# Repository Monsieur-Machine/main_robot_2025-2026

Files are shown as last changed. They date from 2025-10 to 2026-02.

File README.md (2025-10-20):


# Main Robot 2025-2026

## Description
Main robot code, pcbs and 3d modeling for the Eurobot 2025-2026 competition.

## LICENSES
- This project is open-source : you can redistribute and/or modify it under the term of the **GNU GPLv3**.
  Copyright (C) 2025 Riombotique. See [LICENSE](LICENSE) or [gnu.org/licenses/gpl-3.0.html](https://www.gnu.org/licenses/gpl-3.0.html).

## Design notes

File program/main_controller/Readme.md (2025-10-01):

Motion controler code for the RPI Pico (RP2040)
===============================================

This project is the main controller firmware for the RPI Pico (RP2040), designed for the Eurobot 2025 Cup.

I2C description
-----------------------------------------------

The robot’s I2C communication works as follows:
 * Send the device address + R/W bit (to select read or write mode).
 * Send the target register address (to read from or write to).
 * Read or write the register data. Multiple registers can be read/written sequentially, with the address auto-incrementing after each operation.

This code is designed to be the master in the i2c communication.

|Register |R/W|Description |Encoding |
|---|:-:|---|:---:|
| 0x00 | W | Speed motor 1 |**-128** - **127** |
| 0x01 | W | Speed motor 2 |**-128** - **127** |
| 0x02 | W | Speed motor 3 |**-128** - **127** |
| 0x03 | W | Speed motor 4 |**-128** - **127** |
| 0x04 | W | Servo 1 position selection | **0** - **1** |
| 0x05 | W | Servo 2 position selection | **0** - **1** |
| 0x06 | W | Servo 3 position selection | **0** - **1** |
| 0x07 | W | Servo 4 position selection | **0** - **1** |

Motors communication description
-----------------------------------------------

Motors are «connected» to their respective I2C buffer address.

To control a motor you need to write data to its adress of the form :

>```C
>int8_t speed;
>```

Value goes from **-128** to **127**.

Servo motors communication description
-----------------------------------------------

Servo motors are «connected» to their respective I2C buffer address.

To control a servo motor you need to write data to its adress of the form :

>```C
>uint8_t close;
>```

Value is 0 or 1 for the open or the close pos.

Internet communication description
-----------------------------------------------

The robot main_controller is a client connected to the wireless controller which is an udp server host. A buffer is used to store data received from host.

Speed on X and Y axis are not depending of the robot orientation.

Servo motors keep the same byte address in i2c buffer and udp payload.

|Byte |Description |Encoding |
|---|---|:---:|
| 0x00-01 | Robot angle (0x00 is the last significant byte) |**-180** - **180** |
| 0x02 | Speed x axis |**-128** - **127** |
| 0x03 | Speed y axis |**-128** - **127** |
| 0x04 | Servo 1 position selection | **0** - **1** |
| 0x05 | Servo 2 position selection | **0** - **1** |
| 0x06 | Servo 3 position selection | **0** - **1** |
| 0x07 | Servo 4 position selection | **0** - **1** |

Pinout description
-----------------------------------------------

|Pin |Description |GPIO Type  |
|----|---|---|
| 4  | I2C Bus SDA | I2C |
| 5  | I2C Bus SCL | I2C |

Motors placement
-----------------------------------------------

    ,-~***~-,
  /1         2\
 |             |
 |             |
 |             |
  \3         4/
    `-.....-'

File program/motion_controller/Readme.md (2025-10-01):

Motion controler code for the RPI Pico (RP2040)
===============================================

This project is a motion controller firmware for the RPI Pico (RP2040), designed for plug-and-play use with modular code and a clear architecture.

I2C description
-----------------------------------------------

The robot’s I2C communication works as follows:
 * Send the device address + R/W bit (to select read or write mode).
 * Send the target register address (to read from or write to).
 * Read or write the register data. Multiple registers can be read/written sequentially, with the address auto-incrementing after each operation.

This firmware is coded to be a slave when adressed. Its address is **0x09** which you can change if there is any conflict whit other hardware.

|Adress |R/W|Description |Encoding |
|---|:-:|---|:---:|
| 0x00  | W | Speed motor 1 |**-128** - **127** |
| 0x01  | W | Speed motor 2 |**-128** - **127** |
| 0x02  | W | Speed motor 3 |**-128** - **127** |
| 0x03  | W | Speed motor 4 |**-128** - **127** |
| 0x04  | W | Servo 1 position selection | **0** - **1** |
| 0x05  | W | Servo 2 position selection | **0** - **1** |
| 0x06  | W | Servo 3 position selection | **0** - **1** |
| 0x07  | W | Servo 4 position selection | **0** - **1** |

Motors communication description
-----------------------------------------------

Motors are «connected» to their respective I2C buffer address.

To control a motor you need to write data to its adress of the form :

>```C
>int8_t speed;
>```

Value goes from **-128** to **127**.

Servo motors communication description
-----------------------------------------------

Servo motors are «connected» to their respective I2C buffer address.

To control a servo motor you need to write data to its adress of the form :

>```C
>uint8_t close;
>```

Value is 0 or 1 for the open pos or the close pos.

Pinout description
-----------------------------------------------

|Pin |Description |GPIO Type  |
|----|---|---|
| 0  | Motor1 Speed | PWM |
| 1  | Motor2 Speed | PWM |
| 2  | Motor3 Speed | PWM |
| 3  | Motor4 Speed | PWM |
| 4  | Motor1 Dir1 | OUTPUT |
| 5  | Motor1 Dir2 | OUTPUT |
| 6  | Motor2 Dir1 | OUTPUT |
| 7  | Motor2 Dir2 | OUTPUT |
| 8  | Motor3 Dir1 | OUTPUT |
| 9  | Motor3 Dir2 | OUTPUT |
| 10 | Motor4 Dir1 | OUTPUT |
| 11 | Motor5 Dir2 | OUTPUT |
| 12 | Servo1 Angle | PWM |
| 13 | Servo2 Angle | PWM |
| 14 | Servo3 Angle | PWM |
| 15 | Servo4 Angle | PWM |
| 21 | I2C Bus SDA | I2C |
| 20 | I2C Bus SCL | I2C |

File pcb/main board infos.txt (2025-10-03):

# LMZ13608 configuration

Vin min = 9v
Vin max = 12v

Vout = 5v

## Enable resitors
Rent / Renb = (Vin min / 1.274) - 1

Vin min in volt
Rent and Renb same unit and above 5kΩ

Maybe 47kΩ for Rent and 7.75kΩ for Renb

## Output voltage resistors
Rfbt / Rfbb = (Vout / 0.795) – 1

Vout in volt
Rent and Renb in the range of 1.0 kΩ to 10.0 kΩ

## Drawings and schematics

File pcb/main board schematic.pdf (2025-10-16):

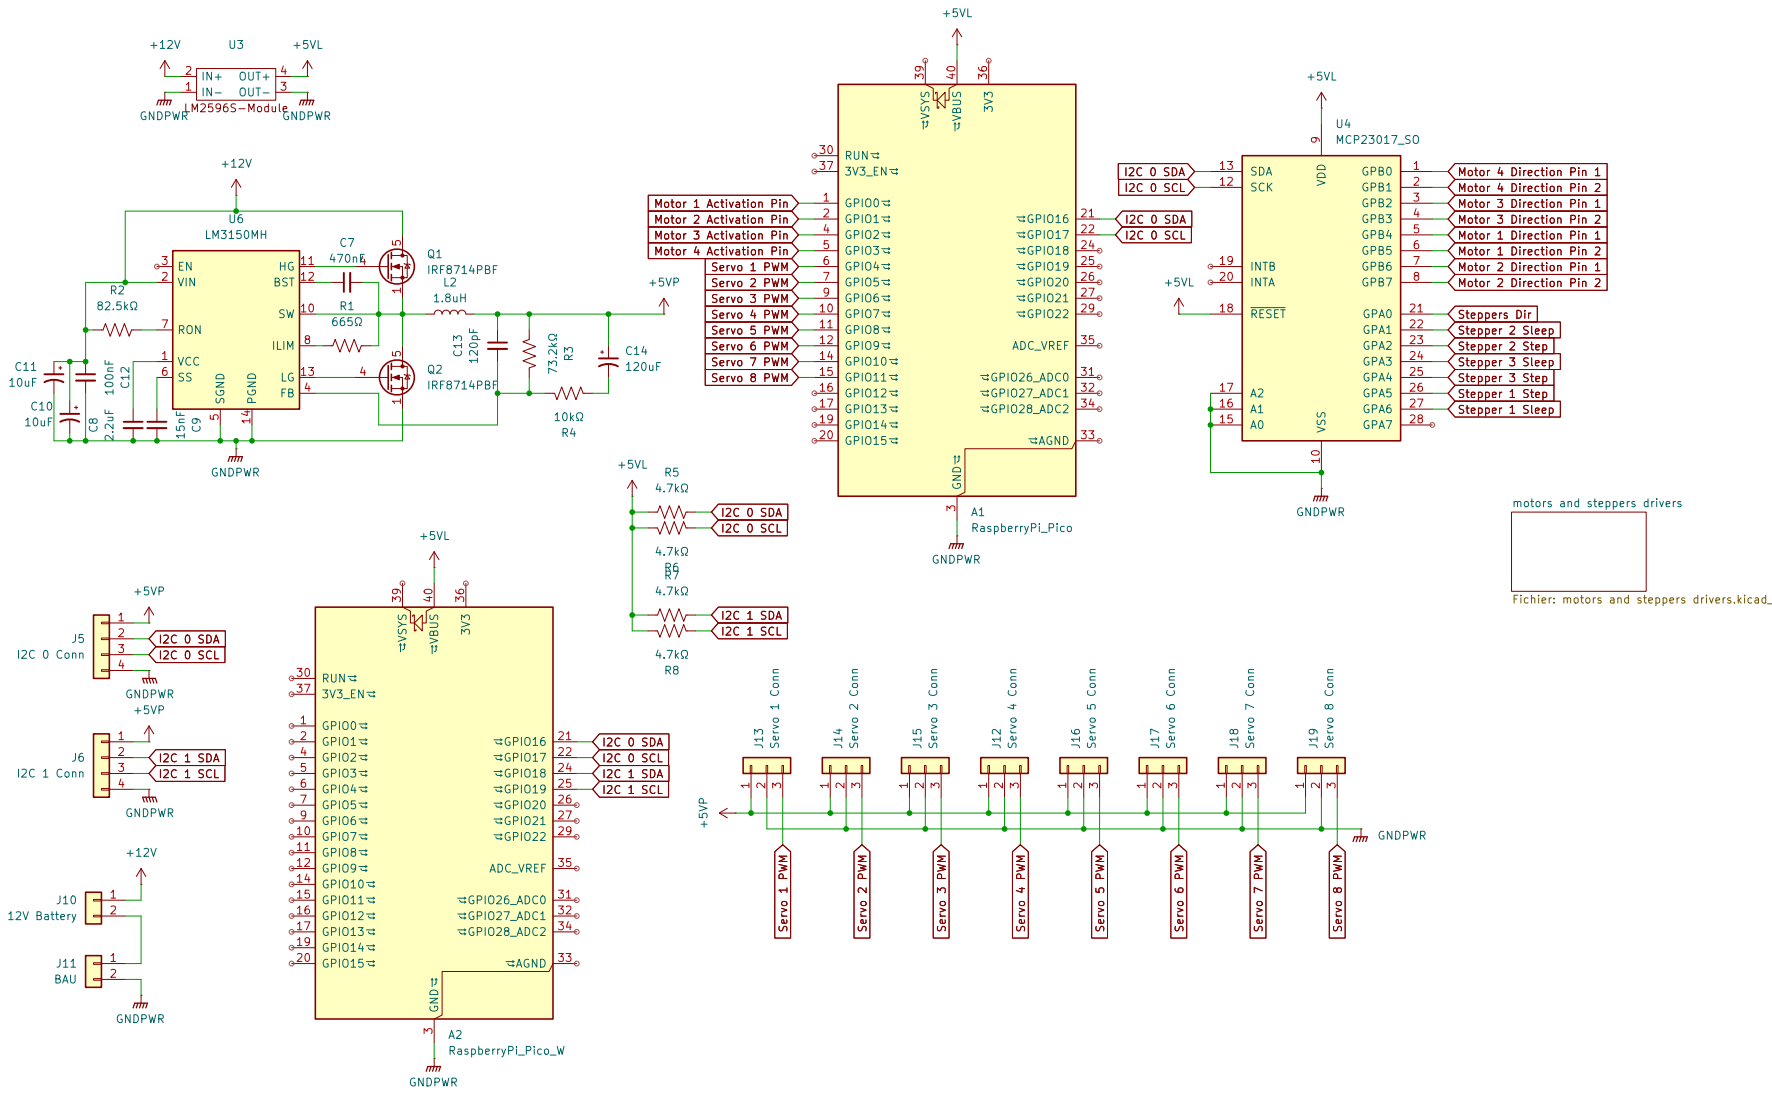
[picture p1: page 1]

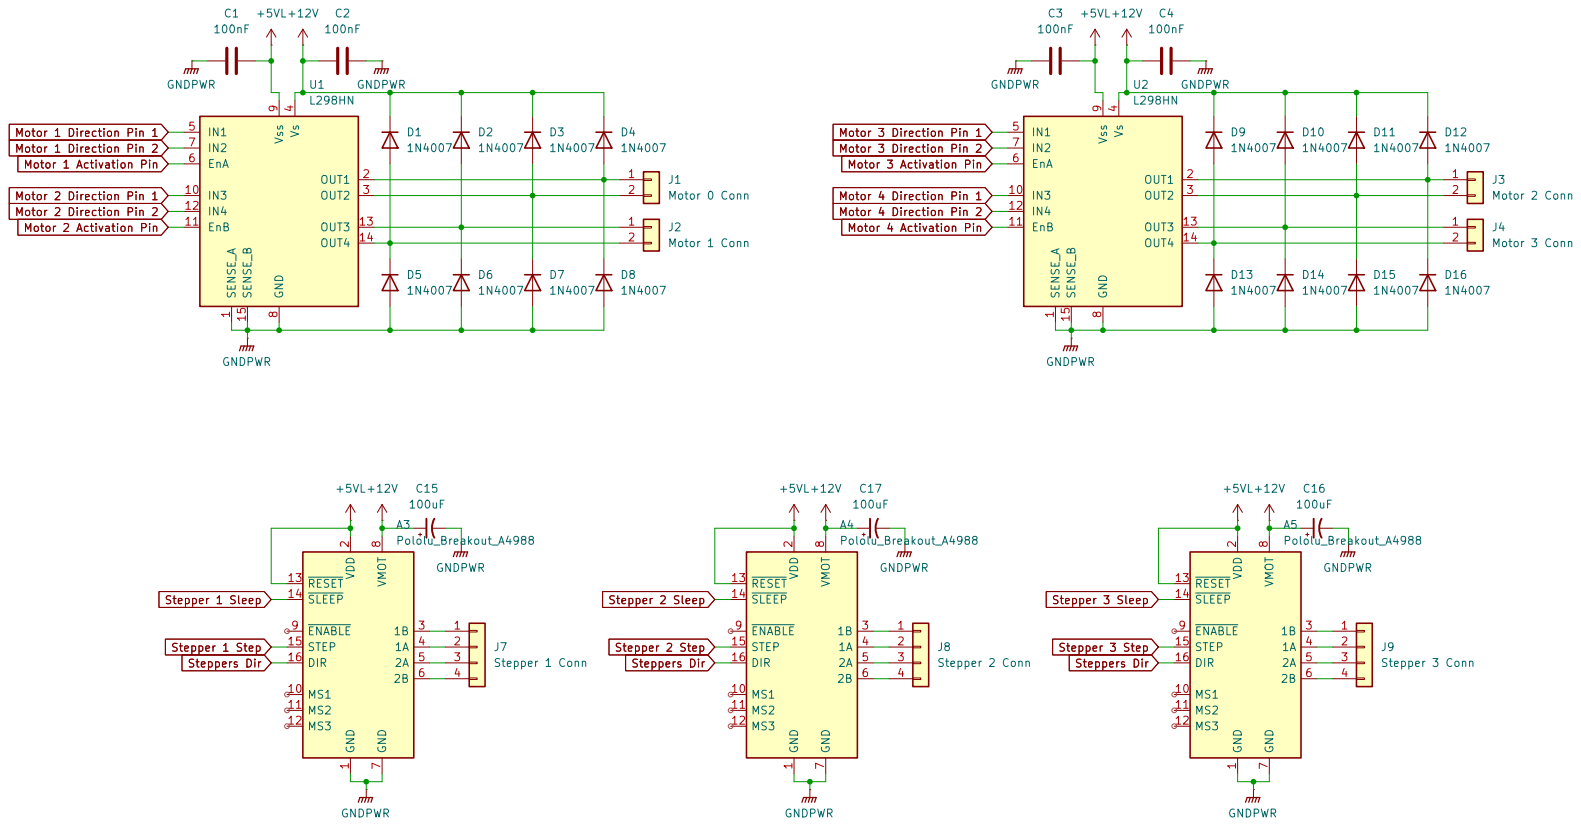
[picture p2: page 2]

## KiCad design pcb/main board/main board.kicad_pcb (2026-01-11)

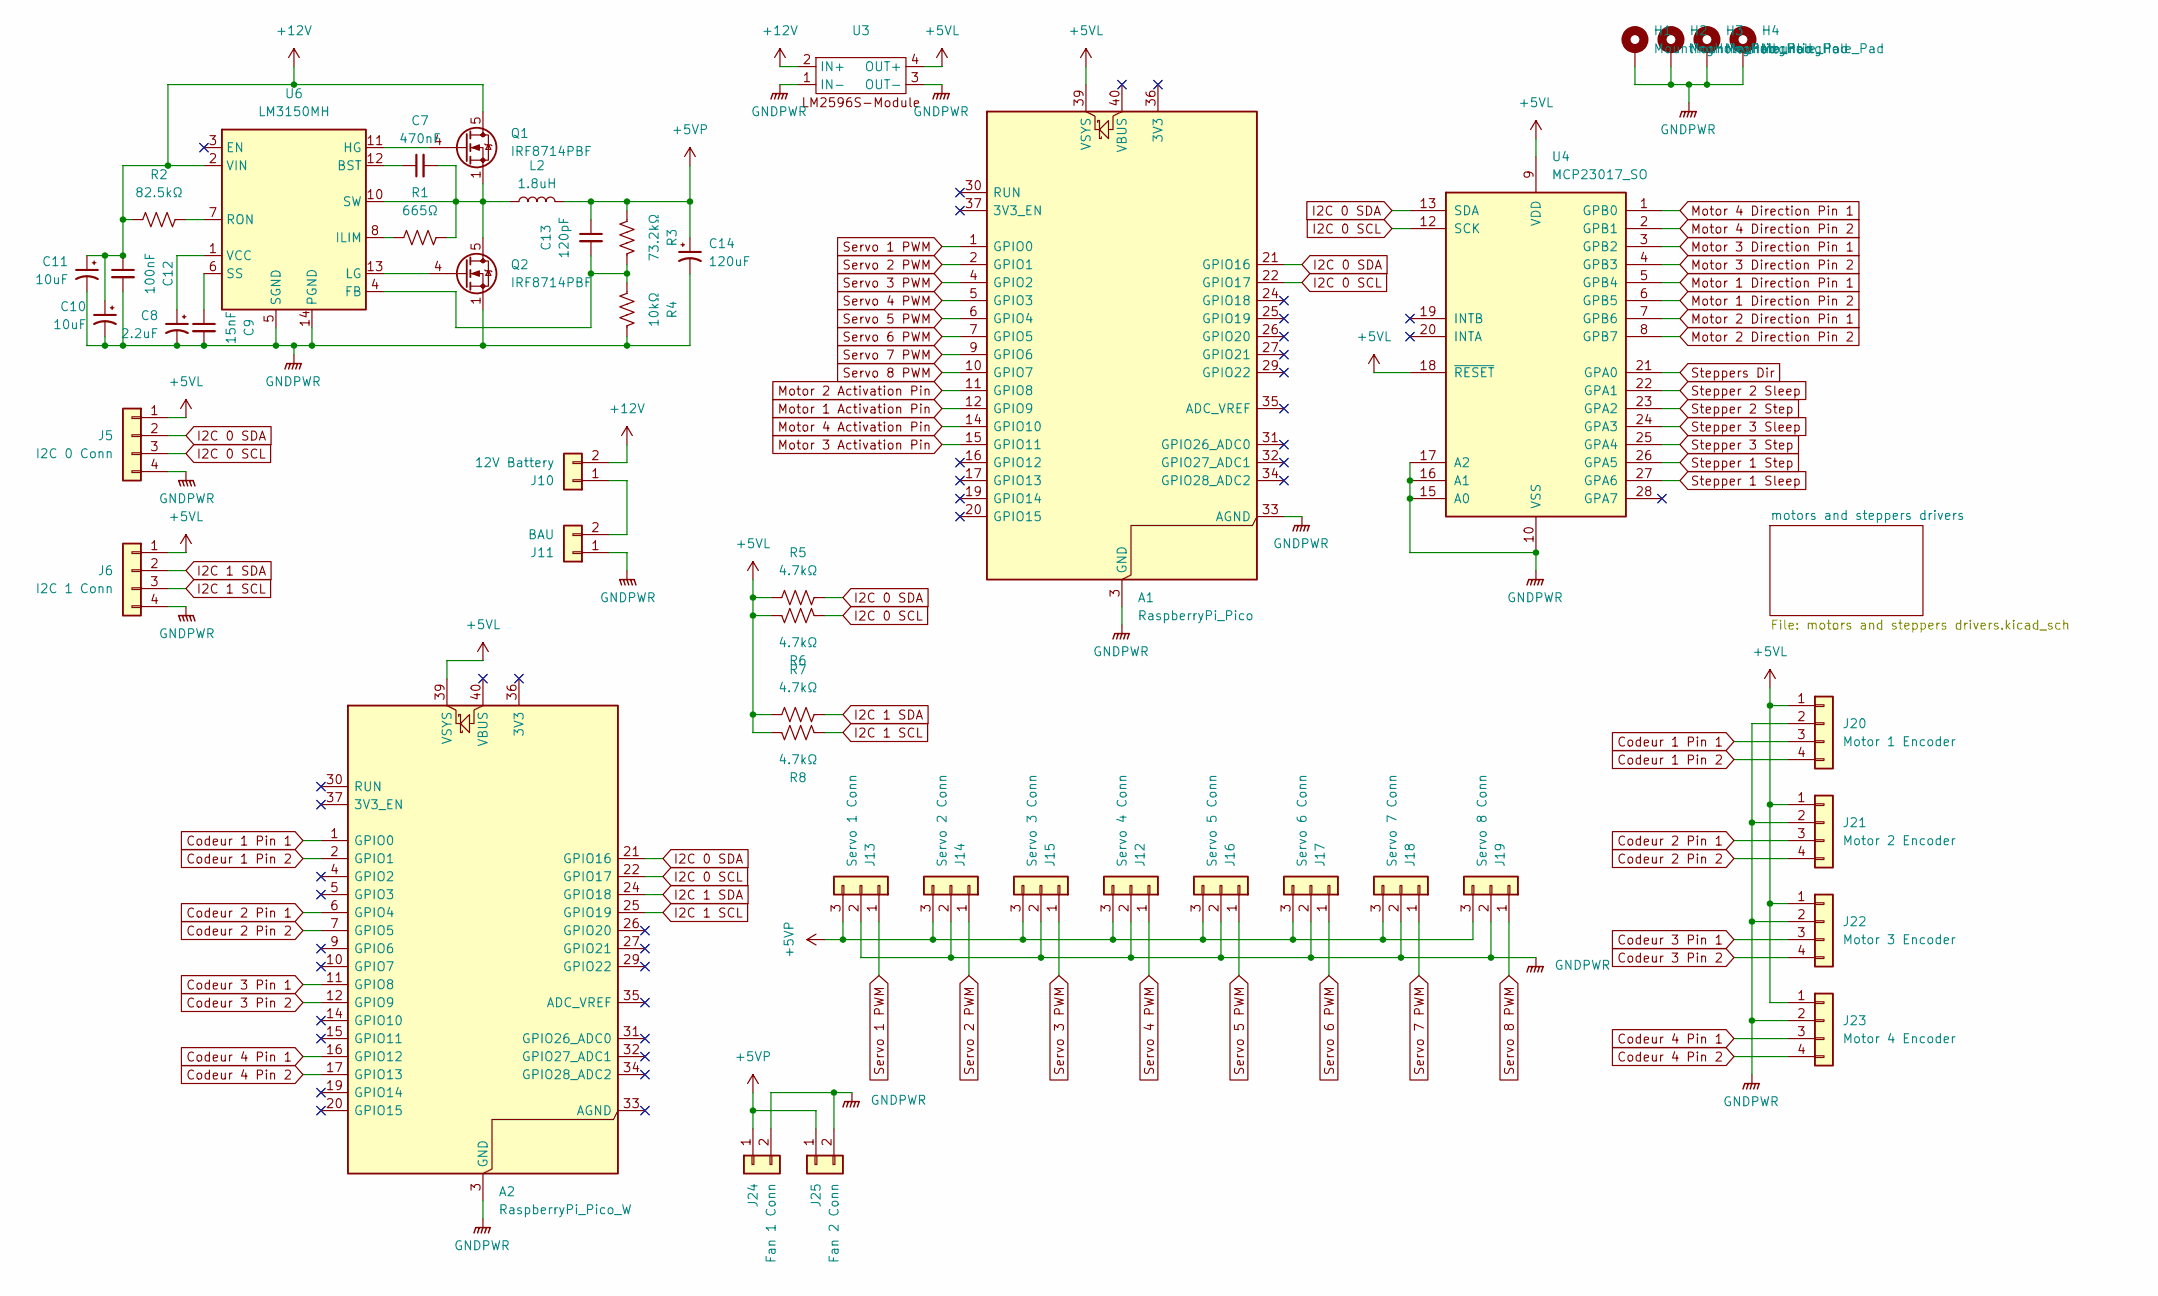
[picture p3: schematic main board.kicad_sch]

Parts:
A1: RaspberryPi_Pico; RaspberryPi_Pico_Common_THT
A2: RaspberryPi_Pico_W; RaspberryPi_Pico_Common_THT
C7: 470nF; C_Disc_D4.3mm_W1.9mm_P5.00mm
C8: 2.2uF; CP_Radial_D5.0mm_P2.00mm
C9: 15nF; C_Disc_D3.8mm_W2.6mm_P2.50mm
C10, C11: 10uF; CP_Radial_D6.3mm_P2.50mm
C12: 100nF; C_Disc_D3.8mm_W2.6mm_P2.50mm
C13: 120pF; C_Disc_D4.3mm_W1.9mm_P5.00mm
C14: 120uF; CP_Radial_D6.3mm_P2.50mm
H1, H2, H3, H4: MountingHole_Pad; MountingHole_4mm_Pad
J5: I2C 0 Conn; Molex_KK-254_AE-6410-04A_1x04_P2.54mm_Vertical
J6: I2C 1 Conn; Molex_KK-254_AE-6410-04A_1x04_P2.54mm_Vertical
J10: 12V Battery; Molex_KK-254_AE-6410-02A_1x02_P2.54mm_Vertical
J11: BAU; Molex_KK-254_AE-6410-02A_1x02_P2.54mm_Vertical
J12: Servo 4 Conn; Molex_KK-254_AE-6410-03A_1x03_P2.54mm_Vertical
J13: Servo 1 Conn; Molex_KK-254_AE-6410-03A_1x03_P2.54mm_Vertical
J14: Servo 2 Conn; Molex_KK-254_AE-6410-03A_1x03_P2.54mm_Vertical
J15: Servo 3 Conn; Molex_KK-254_AE-6410-03A_1x03_P2.54mm_Vertical
J16: Servo 5 Conn; Molex_KK-254_AE-6410-03A_1x03_P2.54mm_Vertical
J17: Servo 6 Conn; Molex_KK-254_AE-6410-03A_1x03_P2.54mm_Vertical
J18: Servo 7 Conn; Molex_KK-254_AE-6410-03A_1x03_P2.54mm_Vertical
J19: Servo 8 Conn; Molex_KK-254_AE-6410-03A_1x03_P2.54mm_Vertical
J20: Motor 1 Encoder; Molex_KK-254_AE-6410-04A_1x04_P2.54mm_Vertical
J21: Motor 2 Encoder; Molex_KK-254_AE-6410-04A_1x04_P2.54mm_Vertical
J22: Motor 3 Encoder; Molex_KK-254_AE-6410-04A_1x04_P2.54mm_Vertical
J23: Motor 4 Encoder; Molex_KK-254_AE-6410-04A_1x04_P2.54mm_Vertical
J24: Fan 1 Conn; Molex_KK-254_AE-6410-02A_1x02_P2.54mm_Vertical
J25: Fan 2 Conn; Molex_KK-254_AE-6410-02A_1x02_P2.54mm_Vertical
L2: 1.8uH; L_APV_APH1040
Q1, Q2: IRF8714PBF; SOIC-8_3.9x4.9mm_P1.27mm
R1: 665Ω; R_Axial_DIN0207_L6.3mm_D2.5mm_P10.16mm_Horizontal
R2: 82.5kΩ; R_Axial_DIN0207_L6.3mm_D2.5mm_P10.16mm_Horizontal
R3: 73.2kΩ; R_Axial_DIN0207_L6.3mm_D2.5mm_P10.16mm_Horizontal
R4: 10kΩ; R_Axial_DIN0207_L6.3mm_D2.5mm_P10.16mm_Horizontal
R5, R6, R7, R8: 4.7kΩ; R_Axial_DIN0207_L6.3mm_D2.5mm_P10.16mm_Horizontal
U3: LM2596S-Module
U4: MCP23017_SO; SOIC-28W_7.5x17.9mm_P1.27mm
U6: LM3150MH; HTSSOP-14-1EP_4.4x5mm_P0.65mm_EP3.4x5mm_Mask3x3.1mm

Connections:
+5VL: A1.39 (VSYS), A2.39 (VSYS), J5.1, J6.1, J20.1, J21.1, J22.1, J23.1, R5.1, R6.1, R7.1, R8.1, U3.4 (OUT+), U4.9 (VDD), U4.18 (~RESET); also elsewhere on the board
+5VP: C13.1, C14.1, J12.3, J13.3, J14.3, J15.3, J16.3, J17.3, J18.3, J19.3, J24.1, J25.1, L2.2, R3.2
+12V: C10.1, C11.1, C12.1, J10.2, Q1.5 (D), Q1.6 (D), Q1.7 (D), Q1.8 (D), R2.1, U3.2 (IN+), U6.2 (VIN); also elsewhere on the board
Codeur 1 Pin 1: A2.1 (GPIO0), J20.3
Codeur 1 Pin 2: A2.2 (GPIO1), J20.4
Codeur 2 Pin 1: A2.6 (GPIO4), J21.3
Codeur 2 Pin 2: A2.7 (GPIO5), J21.4
Codeur 3 Pin 1: A2.11 (GPIO8), J22.3
Codeur 3 Pin 2: A2.12 (GPIO9), J22.4
Codeur 4 Pin 1: A2.16 (GPIO12), J23.3
Codeur 4 Pin 2: A2.17 (GPIO13), J23.4
I2C 0 SCL: A1.22 (GPIO17), A2.22 (GPIO17), J5.3, R6.2, U4.12 (SCK)
I2C 0 SDA: A1.21 (GPIO16), A2.21 (GPIO16), J5.2, R5.2, U4.13 (SDA)
I2C 1 SCL: A2.25 (GPIO19), J6.3, R8.2
I2C 1 SDA: A2.24 (GPIO18), J6.2, R7.2
Motor 1 Activation Pin: A1.12 (GPIO9); also elsewhere on the board
Motor 1 Direction Pin 1: U4.5 (GPB4); also elsewhere on the board
Motor 1 Direction Pin 2: U4.6 (GPB5); also elsewhere on the board
Motor 2 Activation Pin: A1.11 (GPIO8); also elsewhere on the board
Motor 2 Direction Pin 1: U4.7 (GPB6); also elsewhere on the board
Motor 2 Direction Pin 2: U4.8 (GPB7); also elsewhere on the board
Motor 3 Activation Pin: A1.15 (GPIO11); also elsewhere on the board
Motor 3 Direction Pin 1: U4.3 (GPB2); also elsewhere on the board
Motor 3 Direction Pin 2: U4.4 (GPB3); also elsewhere on the board
Motor 4 Activation Pin: A1.14 (GPIO10); also elsewhere on the board
Motor 4 Direction Pin 1: U4.1 (GPB0); also elsewhere on the board
Motor 4 Direction Pin 2: U4.2 (GPB1); also elsewhere on the board
unnamed: J10.1, J11.2
unnamed: Q1.4 (G), U6.11 (HG)
unnamed: Q2.4 (G), U6.13 (LG)
unnamed: C7.1, U6.12 (BST)
unnamed: R1.1, U6.8 (ILIM)
unnamed: R2.2, U6.7 (RON)
unnamed: C9.1, U6.6 (SS)
unnamed: C7.2, L2.1, Q1.1 (S), Q1.2 (S), Q1.3 (S), Q2.5 (D), Q2.6 (D), Q2.7 (D), Q2.8 (D), R1.2, U6.10 (SW)
unnamed: C8.1, U6.1 (VCC)
Servo 1 PWM: A1.1 (GPIO0), J13.1
Servo 2 PWM: A1.2 (GPIO1), J14.1
Servo 3 PWM: A1.4 (GPIO2), J15.1
Servo 4 PWM: A1.5 (GPIO3), J12.1
Servo 5 PWM: A1.6 (GPIO4), J16.1
Servo 6 PWM: A1.7 (GPIO5), J17.1
Servo 7 PWM: A1.9 (GPIO6), J18.1
Servo 8 PWM: A1.10 (GPIO7), J19.1
Stepper 1 Sleep: U4.27 (GPA6); also elsewhere on the board
Stepper 1 Step: U4.26 (GPA5); also elsewhere on the board
Stepper 2 Sleep: U4.22 (GPA1); also elsewhere on the board
Stepper 2 Step: U4.23 (GPA2); also elsewhere on the board
Stepper 3 Sleep: U4.24 (GPA3); also elsewhere on the board
Stepper 3 Step: U4.25 (GPA4); also elsewhere on the board
Steppers Dir: U4.21 (GPA0); also elsewhere on the board

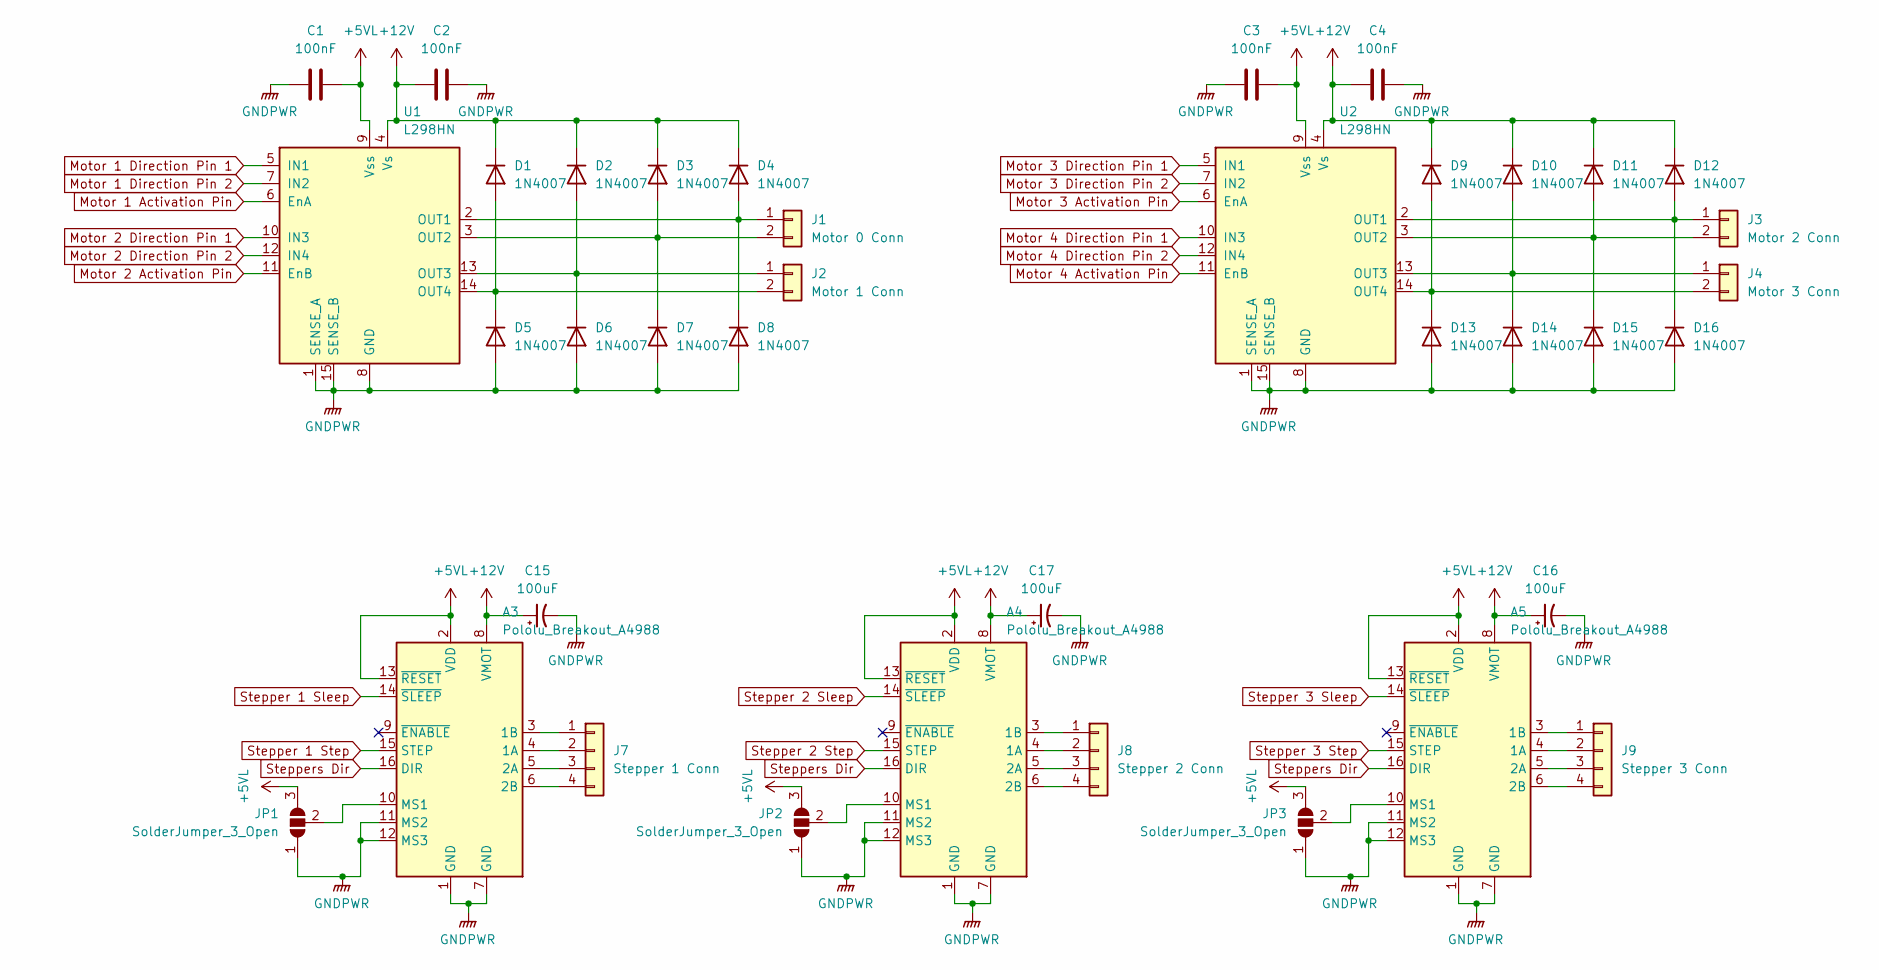
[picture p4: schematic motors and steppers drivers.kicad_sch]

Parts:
A3, A4, A5: Pololu_Breakout_A4988; Pololu_Breakout-16_15.2x20.3mm
C1, C2, C3, C4: 100nF; C_Disc_D4.3mm_W1.9mm_P5.00mm
C15, C16, C17: 100uF; CP_Radial_D6.3mm_P2.50mm
D1, D2, D3, D4, D5, D6, D7, D8, D9, D10, D11, D12, D13, D14, D15, D16: 1N4007; D_DO-41_SOD81_P10.16mm_Horizontal
J1: Motor 0 Conn; Molex_KK-254_AE-6410-02A_1x02_P2.54mm_Vertical
J2: Motor 1 Conn; Molex_KK-254_AE-6410-02A_1x02_P2.54mm_Vertical
J3: Motor 2 Conn; Molex_KK-254_AE-6410-02A_1x02_P2.54mm_Vertical
J4: Motor 3 Conn; Molex_KK-254_AE-6410-02A_1x02_P2.54mm_Vertical
J7: Stepper 1 Conn; Molex_KK-254_AE-6410-04A_1x04_P2.54mm_Vertical
J8: Stepper 2 Conn; Molex_KK-254_AE-6410-04A_1x04_P2.54mm_Vertical
J9: Stepper 3 Conn; Molex_KK-254_AE-6410-04A_1x04_P2.54mm_Vertical
JP1, JP2, JP3: SolderJumper_3_Open; SolderJumper-3_P1.3mm_Open_RoundedPad1.0x1.5mm
U1, U2: L298HN; TO-220-15_P2.54x5.08mm_StaggerOdd_Lead4.58mm_Vertical

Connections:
+5VL: A3.2 (VDD), A3.13 (~RESET), A4.2 (VDD), A4.13 (~RESET), A5.2 (VDD), A5.13 (~RESET), C1.1, C3.2, JP1.3 (B), JP2.3 (B), JP3.3 (B), U1.9 (Vss), U2.9 (Vss); also elsewhere on the board
+12V: A3.8 (VMOT), A4.8 (VMOT), A5.8 (VMOT), C2.2, C4.1, C15.1, C16.1, C17.1, D1.1 (K), D2.1 (K), D3.1 (K), D4.1 (K), D9.1 (K), D10.1 (K), D11.1 (K), D12.1 (K), U1.4 (Vs), U2.4 (Vs); also elsewhere on the board
Motor 1 Activation Pin: U1.6 (EnA); also elsewhere on the board
Motor 1 Direction Pin 1: U1.5 (IN1); also elsewhere on the board
Motor 1 Direction Pin 2: U1.7 (IN2); also elsewhere on the board
Motor 2 Activation Pin: U1.11 (EnB); also elsewhere on the board
Motor 2 Direction Pin 1: U1.10 (IN3); also elsewhere on the board
Motor 2 Direction Pin 2: U1.12 (IN4); also elsewhere on the board
Motor 3 Activation Pin: U2.6 (EnA); also elsewhere on the board
Motor 3 Direction Pin 1: U2.5 (IN1); also elsewhere on the board
Motor 3 Direction Pin 2: U2.7 (IN2); also elsewhere on the board
Motor 4 Activation Pin: U2.11 (EnB); also elsewhere on the board
Motor 4 Direction Pin 1: U2.10 (IN3); also elsewhere on the board
Motor 4 Direction Pin 2: U2.12 (IN4); also elsewhere on the board
unnamed: A3.4 (1A), J7.2
unnamed: A3.3 (1B), J7.1
unnamed: A3.5 (2A), J7.3
unnamed: A3.6 (2B), J7.4
unnamed: A3.10 (MS1), JP1.2 (C)
unnamed: A4.4 (1A), J8.2
unnamed: A4.3 (1B), J8.1
unnamed: A4.5 (2A), J8.3
unnamed: A4.6 (2B), J8.4
unnamed: A4.10 (MS1), JP2.2 (C)
unnamed: A5.4 (1A), J9.2
unnamed: A5.3 (1B), J9.1
unnamed: A5.5 (2A), J9.3
unnamed: A5.6 (2B), J9.4
unnamed: A5.10 (MS1), JP3.2 (C)
unnamed: D1.2 (A), D5.1 (K), J2.2, U1.14 (OUT4)
unnamed: D2.2 (A), D6.1 (K), J2.1, U1.13 (OUT3)
unnamed: D3.2 (A), D7.1 (K), J1.2, U1.3 (OUT2)
unnamed: D4.2 (A), D8.1 (K), J1.1, U1.2 (OUT1)
unnamed: D10.2 (A), D14.1 (K), J4.1, U2.13 (OUT3)
unnamed: D11.2 (A), D15.1 (K), J3.2, U2.3 (OUT2)
unnamed: D12.2 (A), D16.1 (K), J3.1, U2.2 (OUT1)
unnamed: D9.2 (A), D13.1 (K), J4.2, U2.14 (OUT4)
Stepper 1 Sleep: A3.14 (~SLEEP); also elsewhere on the board
Stepper 1 Step: A3.15 (STEP); also elsewhere on the board
Stepper 2 Sleep: A4.14 (~SLEEP); also elsewhere on the board
Stepper 2 Step: A4.15 (STEP); also elsewhere on the board
Stepper 3 Sleep: A5.14 (~SLEEP); also elsewhere on the board
Stepper 3 Step: A5.15 (STEP); also elsewhere on the board
Steppers Dir: A3.16 (DIR), A4.16 (DIR), A5.16 (DIR); also elsewhere on the board

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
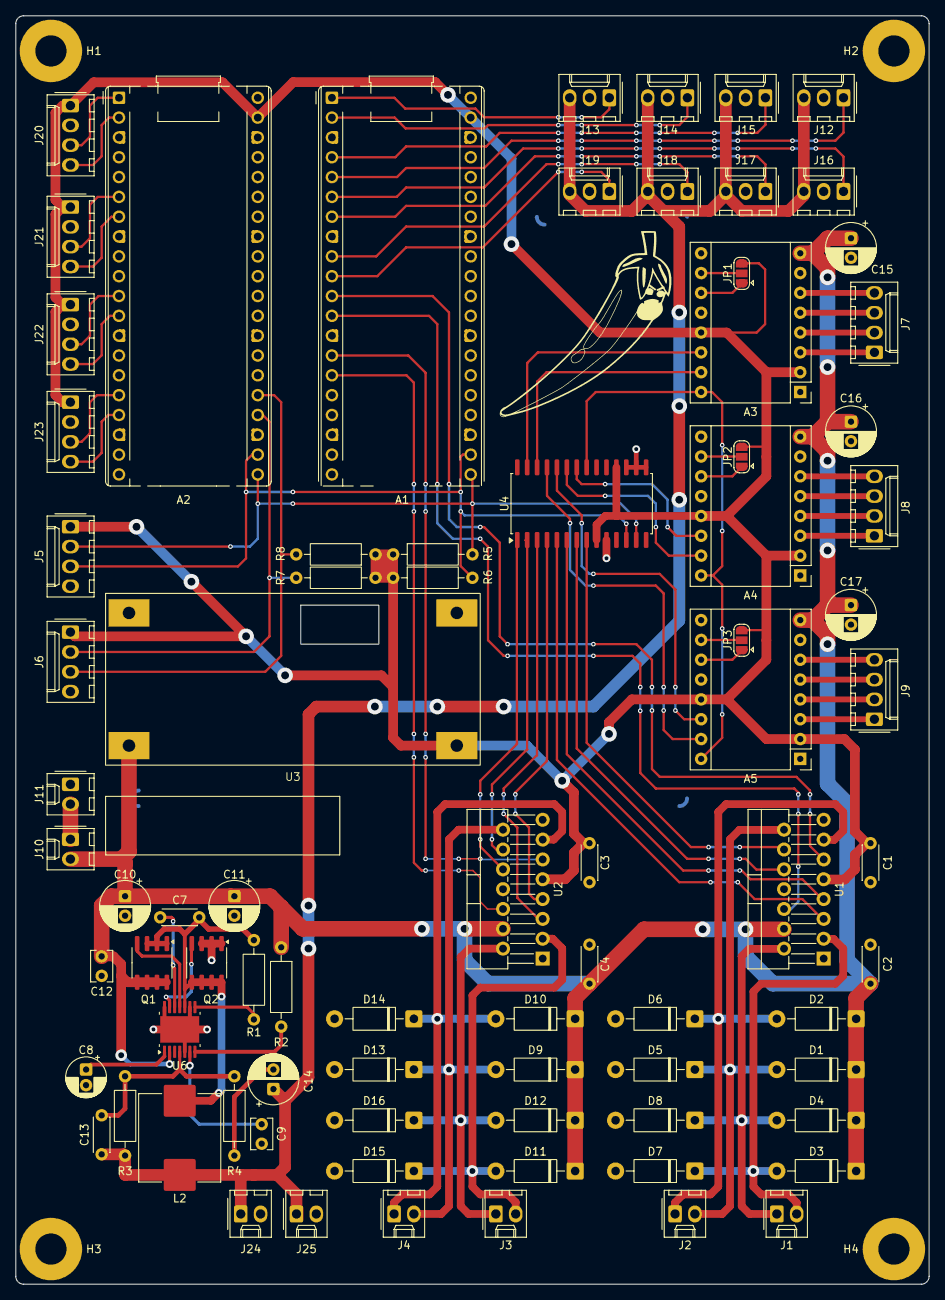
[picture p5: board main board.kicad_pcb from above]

Board: 2 copper layers, 117.0 x 162.5 mm, 84 parts (0 on the bottom side), 76 nets.

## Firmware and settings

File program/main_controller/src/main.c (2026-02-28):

//
//  Copyrights 2025
//          Poivron Robotique
//

/* * * * * * * * * * * * * * * * * * * * * * * * * * * * * * * * * * * * * * * * * *\
*   Code du RPI Pico principale gérant les differentes entrées-sorties.             *
*   Ce Pico est un maitre pilotant le gyroscope, l'internet et le motion controller.*
\* * * * * * * * * * * * * * * * * * * * * * * * * * * * * * * * * * * * * * * * * */

#include "headers/robot.h"

robot_t robot;

int main(void)
{
    robot_init();

    while(robot.is_running)
    {
        robot_update();
    }

    robot_deinit();

    return 0;
}

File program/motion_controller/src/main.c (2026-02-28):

/*                      *\
    Copyrights 2025
            Riombotique
\*                      */

/* * * * * * * * * * * * * * * * * * * * * * * * * * * * * *\
*   Code du RPI Pico gérant les different Actionneurs.      *
*   Ce Pico est un esclave piloté par le Pico Principal.    *
\* * * * * * * * * * * * * * * * * * * * * * * * * * * * * */

#include "headers/robot.h"

robot_t robot;

int main(void)
{
    robot_init();

    while(robot.is_running)
    {
        robot_update();
    }

    robot_deinit();

    return 0;
}

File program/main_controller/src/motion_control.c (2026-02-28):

#include "headers/motion_control.h"

#include <stdio.h>
#include <math.h>
#include <hardware/i2c.h>
#include "i2c/headers/i2c_master.h"
#include "headers/motors.h"
#include "headers/servos.h"
#include "headers/robot.h"

#define ANGLE_PER_S 90.0f
#define GAIN_KP 10

#define MSG_LEN sizeof(uint8_t)                + /*   0x00   */ \
                sizeof(uint8_t)                + /*   LED    */ \
                sizeof(uint8_t)  * NB_MOTORS   + /*  Motors  */ \
                sizeof(uint16_t) * NB_SERVOS     /*  Servos  */

#define MSG_DELAY_MS 2.0f

void motion_control_init(void)
{
    robot.motion_control_data.led_state = false;
    robot.motion_control_data.target_speed = 0;
    robot.motion_control_data.target_angle = 0.0f;
    robot.motion_control_data.motor1_speed = 0;
    robot.motion_control_data.motor2_speed = 0;
}

static inline void motors_control_update(void)
{
    // First we update motion control data from received data
    robot.motion_control_data.target_angle += (float)robot.udp_client.data.hard.inputs.joystick_y / 256.0f * robot.delta_time_ms / 1000.0f * ANGLE_PER_S;
    robot.motion_control_data.target_speed =  robot.udp_client.data.hard.inputs.joystick_x;

    // Go to nearest 90* angle if L button pressed
    if(robot.udp_client.data.hard.inputs.buttons.button_l)
    {
        float angle_offset = fmodf(robot.motion_control_data.target_angle, 90.0f);

        if(fabsf(angle_offset) < 45.0f)
        {
            robot.motion_control_data.target_angle -= angle_offset;
        }
        else
        {
            robot.motion_control_data.target_angle += (90.0f - abs(angle_offset)) * ((angle_offset > 0.0f) - (angle_offset < 0.0f));
        }
    }

    // Wrap angle
    while(robot.motion_control_data.target_angle >  180.0f) robot.motion_control_data.target_angle -= 360.0f;
    while(robot.motion_control_data.target_angle < -180.0f) robot.motion_control_data.target_angle += 360.0f;

    //printf(">target_speed:%d\n", robot.motion_control_data.target_speed);

    float error = robot.motion_control_data.target_angle - robot.gyro_data.x_angle;
    while(error > 180) error -= 360;
    while(error < -180) error += 360;

    float correction = error * GAIN_KP;

    /*printf(">target_angle:%f\n", robot.motion_control_data.target_angle);
    printf(">current_angle:%f\n", robot.gyro_data.x_angle);
    printf(">correction:%f\n", correction);*/

    /*if(correction > 20 && correction < 150){
        correction = 150;
    }
    if(correction < -20 && correction > -150){
        correction = 150;
    }*/

    robot.motion_control_data.motor1_speed = (int16_t)((float)robot.motion_control_data.target_speed - correction);
    robot.motion_control_data.motor2_speed = (int16_t)((float)robot.motion_control_data.target_speed + correction);

    if(robot.motion_control_data.motor1_speed > 255) robot.motion_control_data.motor1_speed = 255;
    if(robot.motion_control_data.motor2_speed > 255) robot.motion_control_data.motor2_speed = 255;

    if(robot.motion_control_data.motor1_speed < -255) robot.motion_control_data.motor1_speed = -255;
    if(robot.motion_control_data.motor2_speed < -255) robot.motion_control_data.motor2_speed = -255;

    // Set dir pins
    motor_set_dir(MOTOR1, robot.motion_control_data.motor1_speed);
    motor_set_dir(MOTOR2, robot.motion_control_data.motor2_speed);
}

static inline void servos_control_update(void)
{
    const uint16_t SERVO1_POSITIONS[5] = {
        500,
        // MORE TO DO
        1950,
    };

    const uint16_t SERVO2_POSITIONS[2] = {
        600,
        2850,
    };

    // XXX DOESN'T WORK ??
    const uint16_t SERVO3_POSITIONS[2] = {
        600,
        2850,
    };
    /*
    // toggle servo 1 pos if button green is pressed
    static float servo1_toggle_elapsed_time = 0.0f;
    servo1_toggle_elapsed_time += robot.delta_time_ms;

    if(robot.udp_client.data.hard.inputs.buttons.button_green && servo1_toggle_elapsed_time >= 200.0f)
    {
        servo1_toggle_elapsed_time = 0.0f;

        servo_set_angle(SERVO1, 90 - robot.servos_data.servos_pos[SERVO1]);
    }
    */
    //servo_set_angle(SERVO3, 400);
}

void steppers_control_update(void)
{
    steppers_set_pos(48);
}

void motion_control_update(void)
{
    motors_control_update();

    servos_control_update();

    steppers_control_update();
}

void motion_control_send(void)
{
    static float elapsed_time_ms = 0.0f;
    elapsed_time_ms += robot.delta_time_ms;

    if(elapsed_time_ms >= MSG_DELAY_MS)
    {
        elapsed_time_ms = 0;
        // Send motors speed via I2C
        uint8_t data[MSG_LEN] = {
            0x00,
            (uint8_t)robot.motion_control_data.led_state,
            (uint8_t)abs(robot.motion_control_data.motor1_speed),
            (uint8_t)abs(robot.motion_control_data.motor2_speed),
            (uint8_t)(robot.servos_data.servos_pos[SERVO1] >> 8) & 0xFF,
            (uint8_t)(robot.servos_data.servos_pos[SERVO1])      & 0xFF,
            (uint8_t)(robot.servos_data.servos_pos[SERVO2] >> 8) & 0xFF,
            (uint8_t)(robot.servos_data.servos_pos[SERVO2])      & 0xFF,
            (uint8_t)(robot.servos_data.servos_pos[SERVO3] >> 8) & 0xFF,
            (uint8_t)(robot.servos_data.servos_pos[SERVO3])      & 0xFF
        };

        if(i2c_write_blocking(I2C_MASTER_INSTANCE, I2C_MOTION_CONTROLLER_ADDRESS, data, MSG_LEN, false) == PICO_ERROR_GENERIC)
        {
            puts("Motion controller not reachable");
        }
    }
}

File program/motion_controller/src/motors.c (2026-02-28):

#include "headers/motors.h"

#include <pico/stdlib.h>
#include <hardware/pwm.h>
#include "headers/robot.h"

#define MOTOR1_PWM_PIN 9
#define MOTOR2_PWM_PIN 8

static inline uint get_motor_pwm_pin(motors_t motor)
{
    switch(motor)
    {
      case MOTOR1:
        return MOTOR1_PWM_PIN;

      case MOTOR2:
        return MOTOR2_PWM_PIN;

      default:
        return -1;
    }
}

static inline void motor_set_speed(motors_t motor, uint8_t value)
{
    uint MOTOR_PWM_PIN = get_motor_pwm_pin(motor);
    pwm_set_gpio_level(MOTOR_PWM_PIN, (uint16_t)value);
}

// Init all motors defined in the MOTORS_DEF array
void motors_init(void)
{
    for(motors_t motor = MOTOR1; motor < NB_MOTORS; motor++)
    {
        // Init PWM
        const uint MOTOR_PWM_PIN = get_motor_pwm_pin(motor);

        const uint SLICE_NUM = pwm_gpio_to_slice_num(MOTOR_PWM_PIN);

        gpio_set_function(MOTOR_PWM_PIN, GPIO_FUNC_PWM);

        pwm_set_clkdiv(SLICE_NUM, 255);
        pwm_set_wrap(SLICE_NUM, 256);

        pwm_set_enabled(SLICE_NUM, true);

        motor_set_speed(motor, 0);
    }
}

void motors_update(void)
{
    motor_set_speed(MOTOR1, robot.i2c_buffer.buffer[I2C_BUFFER_MOTOR1_SPEED]);
    motor_set_speed(MOTOR2, robot.i2c_buffer.buffer[I2C_BUFFER_MOTOR2_SPEED]);
}

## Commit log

2025-10-01 Starting new pcb and copying code from last year main robot
    [main board.kicad_pcb, main board.kicad_sch]
2025-10-01 Added license and removed PCB folder
2025-10-01 Added pico 3D model and started main pcb
    [main board.kicad_sch]
2025-10-01 Started to implement L298N DC Motors drivers
2025-10-02 Finished motor driver on main pcb
    [main board.kicad_sch]
2025-10-02 Added logical 5v regulator schematic
    [main board.kicad_sch]
2025-10-03 Added MCP23017 gpio extender to the motor driver and found a 8A 5v regulator. Neither of them are connected correctly
    [main board.kicad_sch]
2025-10-03 Almost finished implementation of 5v power regulator
    [main board.kicad_sch]
2025-10-03 Finished 5V power alimentation and mcp23017 connection
    [main board.kicad_sch]
2025-10-03 Started to implement steppers motors drivers
    [main board.kicad_sch]
2025-10-03 Finished to implement and connect every 3 steppers drivers
    [main board.kicad_sch]
2025-10-04 Theroricaly finished main board !
    [main board.kicad_pcb, main board.kicad_sch, motors and steppers drivers.kicad_sch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]
2025-10-04 Reformated scheatic size and expoted in pdf
    [main board.kicad_sch]
2025-10-12 Modified LM2596S to be a module.
    [main board.kicad_pcb, main board.kicad_sch, motors and steppers drivers.kicad_sch]
2025-10-12 Changed some capacitors and assigned every component.
    [main board.kicad_sch, motors and steppers drivers.kicad_sch]
2025-10-13 Started Motors Wiring
    [main board.kicad_pcb, main board.kicad_sch, motors and steppers drivers.kicad_sch]
2025-10-13 Finished DC motors wiring aand started 5VP regulator.
    [main board.kicad_pcb, main board.kicad_sch, motors and steppers drivers.kicad_sch]
2025-10-14 Finished DC motors wiring and started 5VP regulator.
    [main board.kicad_pcb, main board.kicad_sch, motors and steppers drivers.kicad_sch]
2025-10-14 Rearanged board
    [main board.kicad_pcb, main board.kicad_sch]
2025-10-14 Finished wiring 5VP, created mass plane and started to wire motor drivers.
    [main board.kicad_pcb, main board.kicad_sch]
2025-10-15 Continued Conecting motors drivers
    [main board.kicad_pcb]
2025-10-15 Almost finished wiring motors drivers and continued connecting the rest. Also modified the LM2596S Module to put a hole in the board
    [main board.kicad_pcb, main board.kicad_sch, motors and steppers drivers.kicad_sch]
2025-10-15 Updated PDF schematic
2025-10-15 Replaced L298Ns footprints to a vertical version and almost finished rewiring them...
    [main board.kicad_pcb]
2025-10-16 Changed largeur of pistes and finished rewiring DC motors drivers
    [main board.kicad_pcb, main board.kicad_sch, motors and steppers drivers.kicad_sch]
2025-10-16 Almost finished PCB !
    [main board.kicad_pcb, main board.kicad_sch]
2025-10-17 Finished PCB !
    [main board.kicad_pcb]
2025-10-17 Added Aisler DRC and corrected errors.
    [main board.kicad_pcb, main board.kicad_sch, motors and steppers drivers.kicad_sch]
2025-10-19 Added motors encoders connectors
    [main board.kicad_pcb, main board.kicad_sch, motors and steppers drivers.kicad_sch]
2025-10-20 Changed empreinte and rewired them to match commanded ones
    [main board.kicad_pcb, main board.kicad_sch]
2025-10-20 Moved component info and hided unused texts
    [main board.kicad_pcb]
2025-10-20 Added logos and aisler logo placeholder
    [main board.kicad_pcb]
2025-10-21 Corrected superposition errors
    [main board.kicad_pcb]
2025-10-26 Added Jumpers To select Steppers speed
    [main board.kicad_pcb, motors and steppers drivers.kicad_sch]
2025-10-27 Finished correcting and updating footprints for capacitors and started to change connectors footprints
    [main board.kicad_pcb, main board.kicad_sch, motors and steppers drivers.kicad_sch]
2025-10-27 Finished adding holes and connectors
    [main board.kicad_pcb, main board.kicad_sch]
2025-11-15 Updated PCB and corrected errors
    [main board.kicad_pcb, main board.kicad_sch]
2025-11-28 Updated PCB
2026-01-11 Staging For Transfer
    [main board.kicad_pcb]
2026-01-31 Corrected WiFi and UDP
    [robot.c]
2026-02-04 Updated pico files and udp communication
2026-02-06 Fixed return state of wifi operator init function
    [main.c, robot.c]
2026-02-09 Lowered I2C bus speed
2026-02-17 Almost working gyro
2026-02-24 Updated gyro and pico files
2026-02-25 Suppression des 200 ms d'attente côté main controler
2026-02-25 Rétablissement du pilotage par gyroscope
2026-02-25 Correction de la tempo qui n'était pas une tempo + suppresion code commenté
    [motion_control.c]
2026-02-28 Working servos (almost) and cleaned robot.h/.c for both controllers

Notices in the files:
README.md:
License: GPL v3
